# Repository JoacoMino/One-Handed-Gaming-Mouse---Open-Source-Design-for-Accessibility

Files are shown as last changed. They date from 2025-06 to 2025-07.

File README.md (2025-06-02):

# One-Handed-Gaming-Mouse---Open-Source-Design-for-Accessibility
Open source files for a low-cost gaming mouse with one-handed use. Includes 3D models, PCB schematics, firmware, and assembly guides to improve gaming accessibility for people with reduced mobility.

# One-Handed Gaming Mouse — Open Source Design for Accessibility

Open source files for a low-cost, one-handed gaming mouse. Includes 3D models, PCB schematics, firmware (Arduino IDE) and assembly guides. Designed to improve gaming accessibility for people with reduced mobility.

## Features
- Fully 3D printable chassis
- Modular design for easy assembly and repair
- Arduino-based firmware (mode: WASD)
- Open source PCB schematics

## Acknowledgements
This project incorporates firmware elements from the PMW3360 module by CitizenJoe (https://www.tindie.com/products/citizenjoe/pmw3360-motion-sensor/), included with purchase of the module and used with permission.

## License
This repository is released under the MIT License. You are free to use, modify, and distribute it for personal or commercial use, provided you include proper attribution.

## Links
- [Project documentation (PDF)](link)
- [Bill of Materials](link)

## Notes
For links to components and suppliers, see the dedicated section in the documentation or in the repository.

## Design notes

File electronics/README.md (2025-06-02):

# Electronics

This folder contains the PCB designs and schematics for the project.

## Included files

- **main-board.sch / .pcb**: Main PCB with the SparkFun Pro Micro, PMW3360 sensor, and connectors.
- **matrix-board.sch / .pcb**: PCB for the 3×4 matrix of mechanical key switches.

## Manufacturing

These PCBs were designed using KiCAD and ordered from a factory in China. Assembly requires:

- Soldering hotswap sockets for key switches.
- Soldering diodes (1N4007 DC) on the matrix board.
- Installing the SparkFun Pro Micro and PMW3360 sensor.

## Components

- 1 SparkFun Pro Micro
- 1 PMW3360 optical sensor module
- 11 Mechanical key switches
- 11 Hotswap sockets
- 11 Diodes 1N4007 DC
- JST connectors for modular assembly

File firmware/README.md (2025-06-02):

# Firmware

This directory contains the Arduino source code (`.ino` file) and required header file (`firmware_data.h`) for the gaming mouse.

## How to use

1. Open the `.ino` file in the Arduino IDE.
2. Make sure the `firmware_data.h` file is in the same folder.
3. Select the correct board and port in the Arduino IDE.
4. Upload the firmware to the SparkFun Pro Micro board.

## Notes

- The firmware implements a one-handed mouse mode (WASD + analog joystick).
- It uses libraries: `SPI.h`, `Keyboard.h`, `Mouse.h`, and `avr/pgmspace.h`.

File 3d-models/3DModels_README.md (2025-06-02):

# 3D Models

This folder contains the 3D design files for the custom parts of the one-handed gaming mouse.

## Included files

- **BaseGeneral.stp**: Main bottom structure providing stability and housing the sensor.
- **SujetaJoystick.stp**: Joystick holder module, adjustable to user's preference.
- **MainBody.stp**: Central body where the electronics and button matrix are integrated.
- **KeycapHolder.stp**: Holder for the mechanical key switches (3×4 matrix).
- **ApoyoMano.stp**: Palm rest to ensure ergonomic support.
- **SeguroApoyo.stp**: Small locking piece for securing the palm rest.
- **FlatKeycap.stp**: Low-profile keycap for minimal vertical height.

Additionally, the entire assembly is provided as:

- **MouseAssembly.f3z**: Complete Fusion 360 assembly file including all the custom components.

## Usage and Printing

- The `.stp` files are designed for easy editing in any CAD software that supports STEP files (e.g., Fusion 360, SolidWorks).
- For 3D printing, you can export any of these files to `.stl` format with your preferred slicing software.
- Material: PLA or similar.
- Layer height: 0.2 mm recommended.
- Infill: 20% for a balance of weight and durability.

## Assembly notes

These parts were designed to be modular and require no adhesives or special tools for assembly. Please refer to the main documentation for exact positioning and mechanical fit.

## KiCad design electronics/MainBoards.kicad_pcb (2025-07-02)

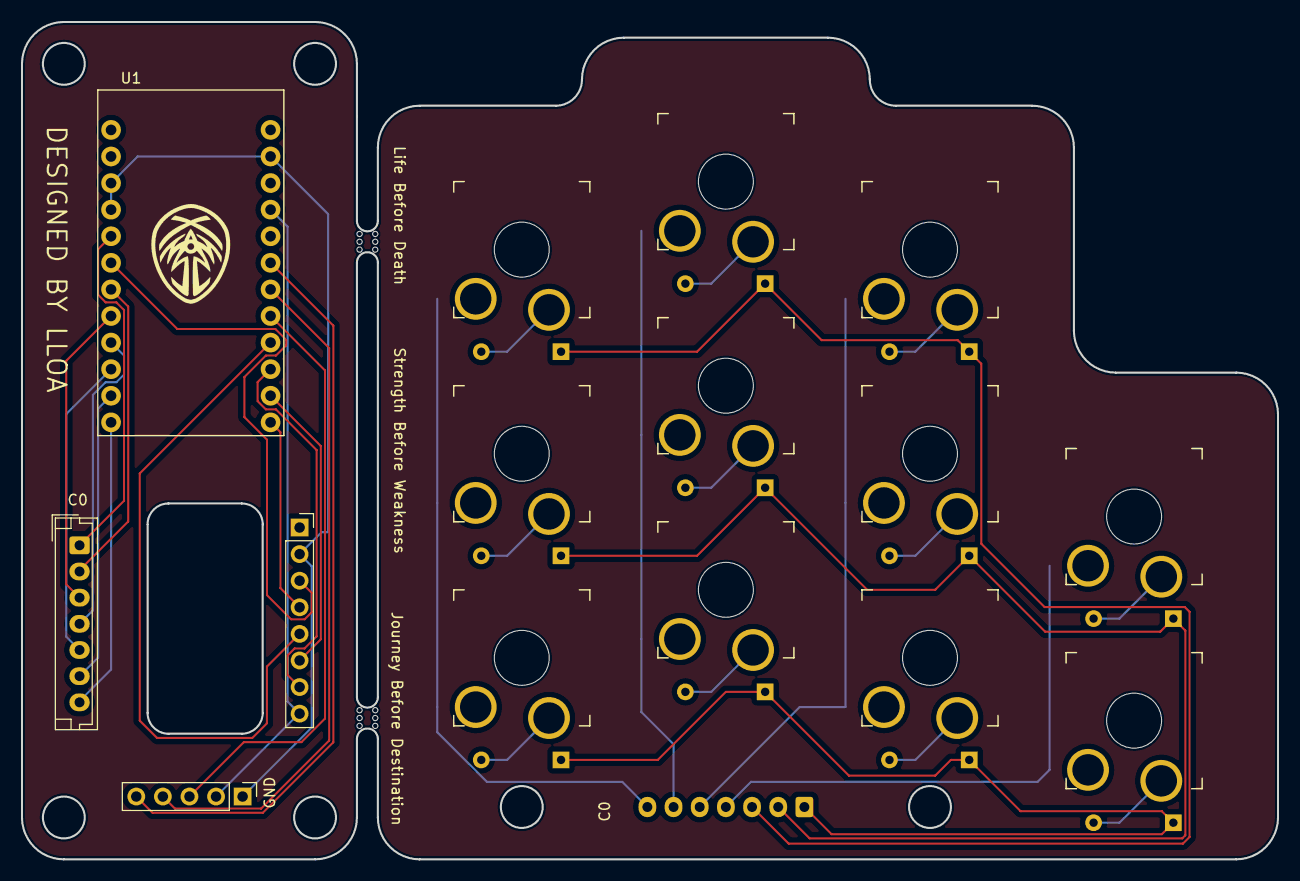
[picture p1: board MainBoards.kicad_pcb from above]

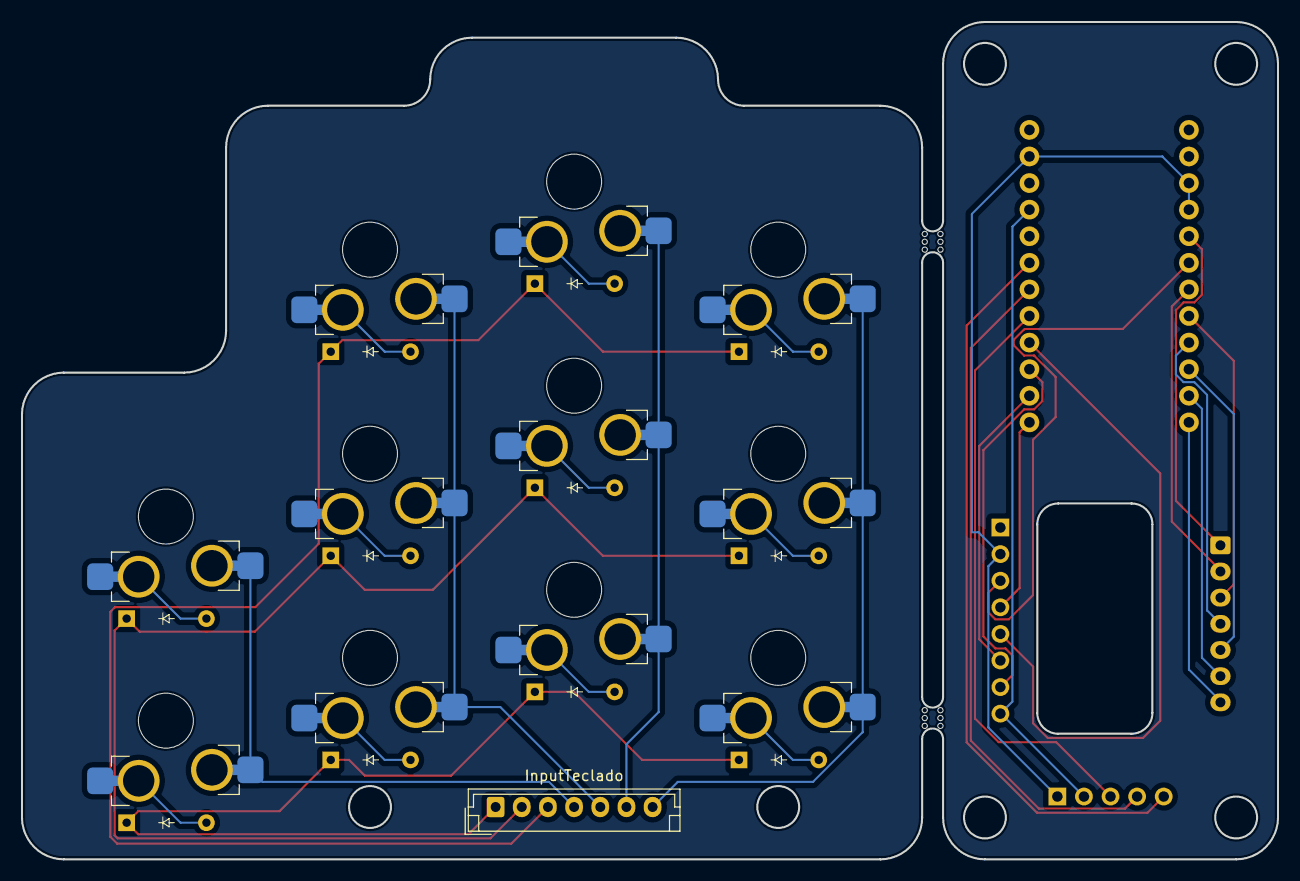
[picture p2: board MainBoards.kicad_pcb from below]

Board: 2 copper layers, 120.0 x 80.0 mm, 29 parts (12 on the bottom side), 35 nets.

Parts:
D1, D2, D3, D4, D5, D6, D7, D8, D9, D10, D11: Diode; Diode_DO-35
InputTeclado: Conn_01x07_Socket; JST_EH_B7B-EH-A_1x07_P2.50mm_Vertical
J2: MouseModule; PinSocket_1x08_P2.54mm_Vertical
J4: JoyStickModule; PinHeader_1x05_P2.54mm_Vertical
J5: OutputTeclado; JST_EH_B7B-EH-A_1x07_P2.50mm_Vertical
S1, S2, S3, S4, S5, S6, S7, S8, S9, S10, S11: Keyswitch; SW_Gateron_LowProfile_HotSwap_PTH
U1: DEV-12587; MODULE_DEV-12587
mouse-bite-2mm-slot, mouse-bite-2mm-slot#2: VAL**; mouse-bite-2mm-slot

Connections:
Column 0: J5.1, U1.JP7_8 (D2)
Column 0 IN: InputTeclado.7, S1.1, S4.1, S8.1
Column 1: J5.2, U1.JP7_6 (D4)
Column 1 IN: InputTeclado.6, S2.1, S5.1, S9.1
Column 2: J5.3, U1.JP7_5 (D5)
Column 2 IN: InputTeclado.5, S3.1, S6.1, S10.1
Column 3: J5.4, U1.JP7_4 (D6)
Column 3 IN: InputTeclado.4, S7.1, S11.1
GROUND: J2.2, J4.1, U1.JP6_2 (GND), U1.JP7_9 (GND), U1.JP7_10 (GND)
MisoModu: J2.7, U1.JP6_10 (MISO)
MosiModu: J2.6, U1.JP6_11 (MOSI)
MtModu: J2.3, U1.JP7_7 (D3)
NcsModu: J2.4, U1.JP6_12 (D10)
unnamed: D1.2 (A), S1.2
unnamed: D2.2 (A), S2.2
unnamed: D3.2 (A), S3.2
unnamed: D4.2 (A), S4.2
unnamed: D5.2 (A), S5.2
unnamed: D6.2 (A), S6.2
unnamed: D7.2 (A), S7.2
unnamed: D8.2 (A), S8.2
unnamed: D9.2 (A), S9.2
unnamed: D10.2 (A), S10.2
unnamed: D11.2 (A), S11.2
Row 0: J5.5, U1.JP7_3 (D7)
Row 0 IN: D1.1 (K), D2.1 (K), D3.1 (K), InputTeclado.3
Row 1: J5.6, U1.JP7_2 (D8)
Row 1 IN: D4.1 (K), D5.1 (K), D6.1 (K), D7.1 (K), InputTeclado.2
Row 2: J5.7, U1.JP7_1 (D9)
Row 2 IN: D8.1 (K), D9.1 (K), D10.1 (K), D11.1 (K), InputTeclado.1
SW JS: J4.5, U1.JP6_6 (A2)
SckModu: J2.5, U1.JP6_9 (SCK)
VRX JS: J4.3, U1.JP6_8 (A0)
VRY JS: J4.4, U1.JP6_7 (A1)
Vin: J2.8, J4.2, U1.JP6_4 (VCC)

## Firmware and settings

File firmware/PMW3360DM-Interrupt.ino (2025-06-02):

/********************************************************************
 *  Ratón-Teclado híbrido · PMW3360 + Joystick + Matriz 3×4
 *  ► Modo WASD (palanca) + Espacio (botón del joystick)
 ********************************************************************/

#include <SPI.h>
#include <Keyboard.h>
#include <Mouse.h>
#include <avr/pgmspace.h>
#include "firmware_data.h"

/* ───── CONFIGURACIÓN GENERAL ──────────────────────────────────── */

// Umbral de zona muerta para el joystick (evita entradas no deseadas por ruido)
const int DEADZONE = 50;

// Sensibilidad de movimiento del ratón (modificable para ajustar velocidad)
float mouseSensitivityX = 0.8;
float mouseSensitivityY = 0.8;

/* ───── DEFINICIÓN DE PINES ────────────────────────────────────── */

const int PIN_SENSOR_NCS     = 10;   // CS del PMW3360
const int PIN_JOYSTICK_X     = A0;   // Eje X del joystick
const int PIN_JOYSTICK_Y     = A1;   // Eje Y del joystick
const int PIN_JOYSTICK_BTN   = A2;   // Botón del joystick
const int PIN_LED_INDICADOR  = 17;   // LED de estado

const int ROW_PINS[3] = {7, 8, 9};   // Pines de filas para la matriz 3x4
const int COL_PINS[4] = {2, 4, 5, 6};// Pines de columnas para la matriz 3x4

/* ───── MAPA DE TECLAS/MOUSE EN MATRIZ ─────────────────────────── */

// Códigos especiales para botones de mouse
#define MOUSE_BTN_LEFT   1
#define MOUSE_BTN_RIGHT  2

const uint16_t keyMap[3][4] = 
{
  { MOUSE_BTN_LEFT,  MOUSE_BTN_RIGHT, 'r',            ' '            },
  { 'q',             'f',             'g',            KEY_LEFT_SHIFT },
  { 'z',             'x',             'c',            KEY_LEFT_CTRL  }
};

/* ───── VARIABLES DE ESTADO ────────────────────────────────────── */

bool wasPressed_W = false, wasPressed_A = false, wasPressed_S = false, wasPressed_D = false;
bool previousMatrixState[3][4];     // Guarda el estado anterior de cada botón en la matriz
bool previousJoystickButton = false; // Guarda el estado anterior del botón del joystick

/* ───── FUNCIONES AUXILIARES PARA EL SENSOR PMW3360 ───────────── */

void adns_com_begin()
{
  digitalWrite(PIN_SENSOR_NCS, LOW);
}

void adns_com_end()
{
  digitalWrite(PIN_SENSOR_NCS, HIGH);
}

byte adns_read_reg(byte reg)
{
  adns_com_begin();
  SPI.transfer(reg & 0x7F);
  delayMicroseconds(100);
  byte data = SPI.transfer(0);
  delayMicroseconds(1);
  adns_com_end();
  delayMicroseconds(19);
  return data;
}

void adns_write_reg(byte reg, byte value)
{
  adns_com_begin();
  SPI.transfer(reg | 0x80);
  SPI.transfer(value);
  delayMicroseconds(20);
  adns_com_end();
  delayMicroseconds(100);
}

void adns_upload_firmware()
{
  adns_write_reg(0x10, 0x20);
  adns_write_reg(0x13, 0x1D);
  delay(10);
  adns_write_reg(0x13, 0x18);

  adns_com_begin();
  SPI.transfer(0x62 | 0x80);
  delayMicroseconds(15);

  for (unsigned short i = 0; i < firmware_length; i++)
  {
    SPI.transfer(pgm_read_byte(firmware_data + i));
    delayMicroseconds(15);
  }

  adns_com_end();

  adns_read_reg(0x2A);
  adns_write_reg(0x10, 0x00);
  adns_write_reg(0x0F, 0x15);
}

void adns_initialize()
{
  adns_com_end();
  adns_com_begin();
  adns_com_end();

  adns_write_reg(0x3A, 0x5A);
  delay(50);

  // Leer registros para iniciar el sensor
  adns_read_reg(0x02);
  adns_read_reg(0x03);
  adns_read_reg(0x04);
  adns_read_reg(0x05);
  adns_read_reg(0x06);

  adns_upload_firmware();
  delay(10);
}

void readSensorMotion(int16_t &dx, int16_t &dy)
{
  adns_write_reg(0x02, 0x01); // Trigger motion burst
  adns_read_reg(0x02);        // Dummy read

  byte dxL = adns_read_reg(0x03);
  byte dxH = adns_read_reg(0x04);
  byte dyL = adns_read_reg(0x05);
  byte dyH = adns_read_reg(0x06);

  dx = (int16_t)(((uint16_t)dxH << 8) | dxL);
  dy = (int16_t)(((uint16_t)dyH << 8) | dyL);
}

/* ───── SETUP ──────────────────────────────────────────────────── */

void setup()
{
  Keyboard.begin();
  Mouse.begin();
  Serial.begin(115200);

  pinMode(PIN_SENSOR_NCS, OUTPUT);
  digitalWrite(PIN_SENSOR_NCS, HIGH);

  SPI.begin();
  SPI.setDataMode(SPI_MODE3);
  SPI.setBitOrder(MSBFIRST);
  SPI.setClockDivider(SPI_CLOCK_DIV64);

  adns_initialize();

  pinMode(PIN_JOYSTICK_BTN, INPUT_PULLUP);
  pinMode(PIN_LED_INDICADOR, OUTPUT);
  digitalWrite(PIN_LED_INDICADOR, LOW);

  // Inicialización de pines de la matriz 3x4
  for (int r = 0; r < 3; r++)
  {
    pinMode(ROW_PINS[r], OUTPUT);
    digitalWrite(ROW_PINS[r], HIGH);
  }

  for (int c = 0; c < 4; c++)
  {
    pinMode(COL_PINS[c], INPUT_PULLUP);
  }

  // Inicializar estados anteriores de los botones
  for (int r = 0; r < 3; r++)
  {
    for (int c = 0; c < 4; c++)
    {
      previousMatrixState[r][c] = false;
    }
  }
}

/* ───── LOOP PRINCIPAL ─────────────────────────────────────────── */

void loop()
{
  /* 1. Movimiento del ratón con sensor óptico -------------------- */
  int16_t deltaX = 0, deltaY = 0;
  readSensorMotion(deltaX, deltaY);

  signed char moveX = constrain((int)(deltaX * mouseSensitivityX), -127, 127);
  signed char moveY = constrain((int)(deltaY * mouseSensitivityY), -127, 127);

  if (moveX || moveY)
  {
    Mouse.move(moveX, moveY);
  }

  /* 2. Botón del joystick para salto (espacio) ------------------- */
  bool currentJoystickButton = (digitalRead(PIN_JOYSTICK_BTN) == LOW);

  if (currentJoystickButton && !previousJoystickButton)
  {
    Keyboard.press(' ');
  }
  else if (!currentJoystickButton && previousJoystickButton)
  {
    Keyboard.release(' ');
  }

  previousJoystickButton = currentJoystickButton;

  /* 3. Movimiento tipo WASD con el joystick ---------------------- */
  int joyX = analogRead(PIN_JOYSTICK_X) - 512;
  int joyY = analogRead(PIN_JOYSTICK_Y) - 512;

  bool pressW = false, pressA = false, pressS = false, pressD = false;

  if (joyY >  DEADZONE) pressD = true; // Derecha
  if (joyY < -DEADZONE) pressA = true; // Izquierda
  if (joyX >  DEADZONE) pressW = true; // Adelante
  if (joyX < -DEADZONE) pressS = true; // Atrás

  if (pressW && !wasPressed_W)       Keyboard.press('w'); else if (!pressW && wasPressed_W)       Keyboard.release('w');
  if (pressA && !wasPressed_A)       Keyboard.press('a'); else if (!pressA && wasPressed_A)       Keyboard.release('a');
  if (pressS && !wasPressed_S)       Keyboard.press('s'); else if (!pressS && wasPressed_S)       Keyboard.release('s');
  if (pressD && !wasPressed_D)       Keyboard.press('d'); else if (!pressD && wasPressed_D)       Keyboard.release('d');

  wasPressed_W = pressW;
  wasPressed_A = pressA;
  wasPressed_S = pressS;
  wasPressed_D = pressD;

  /* 4. Lectura de matriz de botones ------------------------------ */
  for (int r = 0; r < 3; r++)
  {
    digitalWrite(ROW_PINS[r], LOW);
    delayMicroseconds(5);

    for (int c = 0; c < 4; c++)
    {
      bool pressed = (digitalRead(COL_PINS[c]) == LOW);

      uint16_t code = keyMap[r][c];

      if (pressed && !previousMatrixState[r][c])
      {
        if (code == MOUSE_BTN_LEFT)        Mouse.press(MOUSE_LEFT);
        else if (code == MOUSE_BTN_RIGHT)  Mouse.press(MOUSE_RIGHT);
        else                               Keyboard.press((uint8_t)code);
      }
      else if (!pressed && previousMatrixState[r][c])
      {
        if (code == MOUSE_BTN_LEFT)        Mouse.release(MOUSE_LEFT);
        else if (code == MOUSE_BTN_RIGHT)  Mouse.release(MOUSE_RIGHT);
        else                               Keyboard.release((uint8_t)code);
      }

      previousMatrixState[r][c] = pressed;
    }

    digitalWrite(ROW_PINS[r], HIGH);
  }

  delay(1); // Pequeña pausa para evitar rebotes
}
